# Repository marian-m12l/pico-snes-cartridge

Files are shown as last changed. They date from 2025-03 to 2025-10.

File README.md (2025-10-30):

# RP2350-based SNES cartridge

launcher

https://github.com/user-attachments/assets/8309a93a-a673-430d-9ed4-e411bfe92a66

snes_cart_1
snes_cart_2

## Pins

On rp2350 board (e.g. PGA2350):

- Address bus `A0`-`A23`: GPIO 0 (`A0`) to 23 (`A23`)
- Data bus `D0`-`D7`: GPIO 24 (`D0`) to 31 (`D7`)
- Cart pin `/CART`: GPIO 32
- Read pin `/RD`: GPIO 33
- Reset pin `/RESET`: GPIO 35
- CIC pin 24 `D1`: GPIO 37
- CIC pin 55 `D2`: GPIO 38
- CIC pin 56 `CLK`: GPIO 39
- CIC pin 25 `RST`: GPIO 40

- UART pins `TX` and `RX`: GPIO 44 and 45

## Build instructions

```
mkdir build
cd build
cmake -DPICO_SDK_PATH=/path/to/pico-sdk-2.1.0 -DPICO_BOARD=pimoroni_pga2350 ..
make
```

# Adding ROMs

Add `rom.sfc` in slot `1`:
```
./tools/loadrom.sh rom.sfc 1"
```

Each slot (from 1 to 15) occupies 1MiB in flash memory.

# Running

```
$ openocd-rpi/installed/bin/openocd -f interface/jlink.cfg -c "transport select swd" -c "adapter speed 6000" -f target/rp2350.cfg
$ arm-none-eabi-gdb -ex 'target remote localhost:3333' -ex 'load' -ex 'monitor reset init' -ex 'continue' pico-snes-cartridge.elf
$ picocom -b 115200 /dev/ttyACM0 -g picocom.log
```

# Reset behaviour

Once you've selected a game, pressing the reset button on the SNES will restart this game.

A long-press (~1 second) will go back to the launcher.

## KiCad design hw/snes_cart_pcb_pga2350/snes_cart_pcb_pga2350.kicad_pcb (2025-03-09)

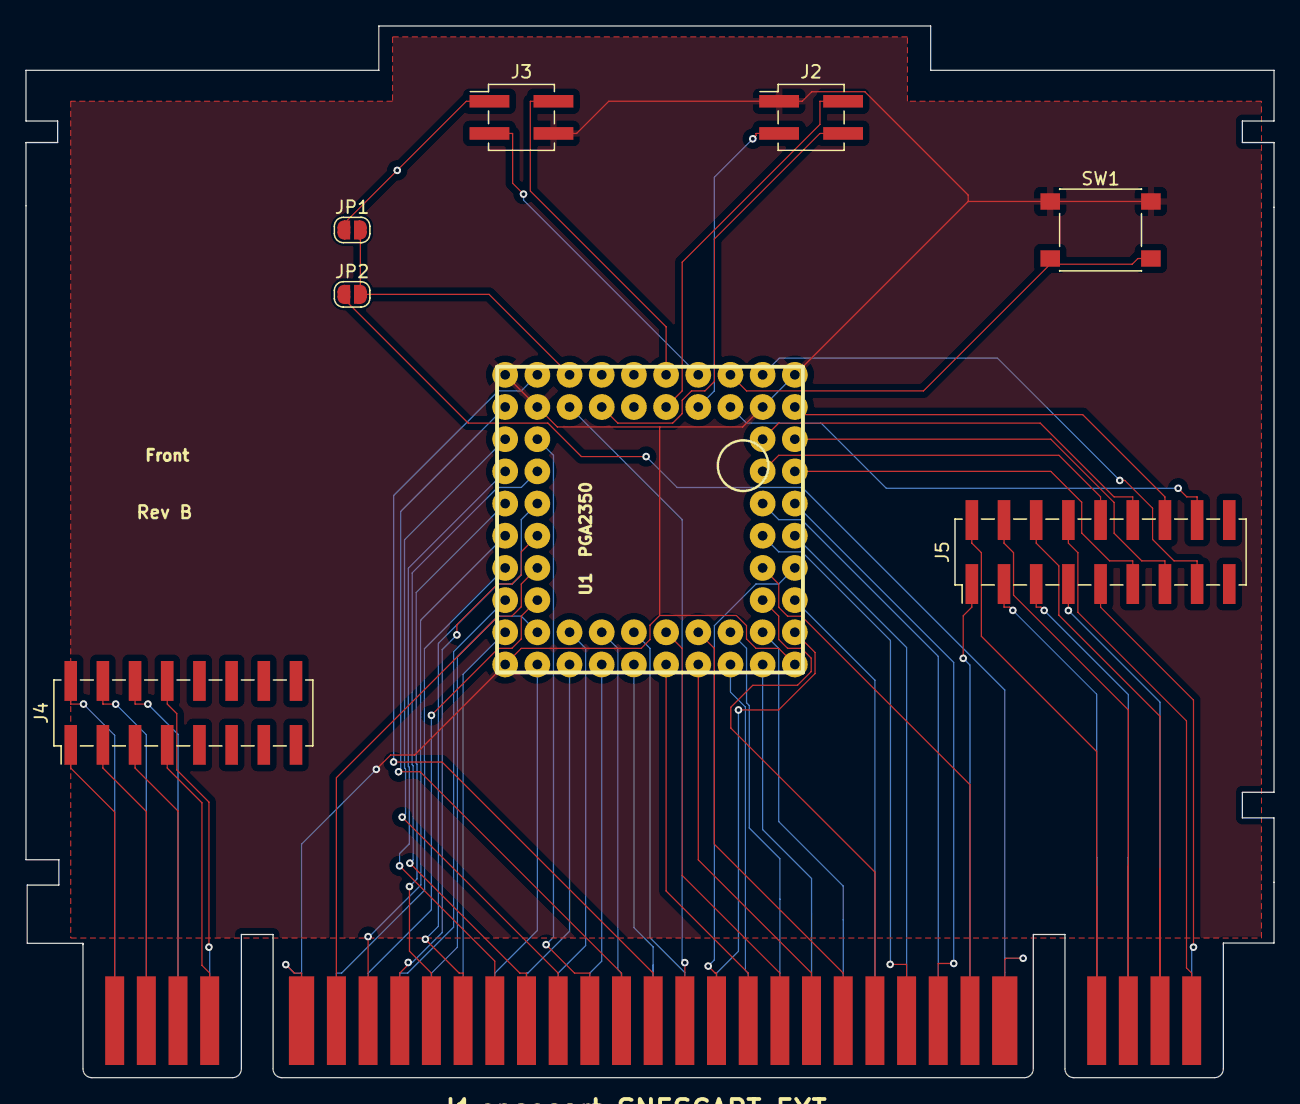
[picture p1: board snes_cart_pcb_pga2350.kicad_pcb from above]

Board: 2 copper layers, 98.5 x 83.0 mm, 9 parts (0 on the bottom side), 75 nets.

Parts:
J1: snescart_SNESCART_EXT; SNESCART_EXT_100mm
J2, J3: Conn_02x02_Counter_Clockwise; PinHeader_2x02_P2.54mm_Vertical_SMD
J4: Conn_02x08_Counter_Clockwise; PinHeader_2x08_P2.54mm_Vertical_SMD
J5: Conn_02x09_Counter_Clockwise; PinHeader_2x09_P2.54mm_Vertical_SMD
JP1, JP2: SolderJumper_2_Open; SolderJumper-2_P1.3mm_Open_RoundedPad1.0x1.5mm
SW1: SW_Push; SW_Push_1P1T_NO_6x6mm_H9.5mm
U1: PGA2350

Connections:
/3V3: J2.4, U1.B4 (PIN)
/A0: J1.17 (A0), U1.B3 (PIN)
/A1: J1.16 (A1), U1.A2 (PIN)
/A2: J1.15 (A2), U1.B1 (PIN)
/A3: J1.14 (A3), U1.C2 (PIN)
/A4: J1.13 (A4), U1.C1 (PIN)
/A5: J1.12 (A5), U1.D2 (PIN)
/A6: J1.11 (A6), U1.D1 (PIN)
/A7: J1.10 (A7), U1.E2 (PIN)
/A8: J1.9 (A8), U1.E1 (PIN)
/A9: J1.8 (A9), U1.F2 (PIN)
/A10: J1.7 (A10), U1.F1 (PIN)
/A11: J1.6 (A11), U1.G2 (PIN)
/A12: J1.37 (A12), U1.G1 (PIN)
/A13: J1.38 (A13), U1.H2 (PIN)
/A14: J1.39 (A14), U1.H1 (PIN)
/A15: J1.40 (A15), U1.J2 (PIN)
/A16: J1.41 (A16), U1.J1 (PIN)
/A17: J1.42 (A17), U1.K2 (PIN)
/A18: J1.43 (A18), U1.K3 (PIN)
/A19: J1.44 (A19), U1.J3 (PIN)
/A20: J1.45 (A20), U1.K4 (PIN)
/A21: J1.46 (A21), U1.J4 (PIN)
/A22: J1.47 (A22), U1.K5 (PIN)
/A23: J1.48 (A23), U1.J5 (PIN)
/BOOTSEL: SW1.2, U1.A8 (PIN)
/CIC_P1_DOUT: J1.24 (CIC_P1_DOUT), U1.F9 (PIN)
/CIC_P2_DIN: J1.55 (CIC_P2_DIN), U1.F10 (PIN)
/CIC_P6_CLK: J1.56 (CIC_P6_CLK), U1.E9 (PIN)
/CIC_P7_RESET: J1.25 (CIC_P7_RESET), U1.E10 (PIN)
/CPU_CLK: J1.57 (CPU_CLK), J5.1
/D0: J1.19 (D0), U1.K6 (PIN)
/D1: J1.20 (D1), U1.J6 (PIN)
/D2: J1.21 (D2), U1.K7 (PIN)
/D3: J1.22 (D3), U1.J7 (PIN)
/D4: J1.50 (D4), U1.K8 (PIN)
/D5: J1.51 (D5), U1.J8 (PIN)
/D6: J1.52 (D6), U1.K9 (PIN)
/D7: J1.53 (D7), U1.J9 (PIN)
/EXPAND: J1.2 (EXPAND), J4.3
/GND: J1.5 (GND), J1.36 (GND), J2.1, J3.4, SW1.1, U1.A1 (PIN), U1.A10 (PIN), U1.B2 (PIN), U1.B9 (PIN), U1.K1 (PIN), U1.K10 (PIN)
/GP41: J5.10, U1.D9 (PIN)
/GP42: J5.11, U1.D10 (PIN)
/GP43: J5.12, U1.C9 (PIN)
/GP44: J5.13, U1.C10 (PIN)
/GP45: J5.14, U1.B10 (PIN)
/GP46: J5.15, U1.A9 (PIN)
/GP47: J5.16, U1.B8 (PIN)
/LINE_L: J1.31 (LINE_L), J5.8
/LINE_R: J1.62 (LINE_R), J5.9
/PA0: J1.28 (PA0), J5.2
/PA1: J1.59 (PA1), J5.3
/PA2: J1.29 (PA2), J5.4
/PA3: J1.60 (PA3), J5.5
/PA4: J1.30 (PA4), J5.6
/PA5: J1.61 (PA5), J5.7
/PA6: J1.3 (PA6), J4.5
/PA7: J1.34 (PA7), J4.6
/REFRESH: J1.33 (REFRESH), J4.4
/SWCLK: J2.2, U1.B6 (PIN)
/SWDIO: J2.3, U1.B7 (PIN)
/SYS_CLK: J1.1 (SYS_CLK), J4.1
/USB_DM: J3.3, U1.A7 (PIN)
/USB_DP: J3.2, U1.A6 (PIN)
/USB_VBUS: J3.1, JP1.1 (A)
/VBUS: JP1.2 (B), JP2.2 (B), U1.A3 (PIN)
/VCC: J1.27 (VCC), J1.58 (VCC), JP2.1 (A)
//IRQ: J1.18 (/IRQ), U1.G10 (PIN)
//PARD: J1.4 (/PARD), J4.7
//PAWR: J1.35 (/PAWR), J4.8
//RD: J1.23 (/RD), U1.H9 (PIN)
//RESET: J1.26 (/RESET), U1.G9 (PIN)
//ROMSEL: J1.49 (/ROMSEL), U1.J10 (PIN)
//WR: J1.54 (/WR), U1.H10 (PIN)
//WRAM: J1.32 (/WRAM), J4.2

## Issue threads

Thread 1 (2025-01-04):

Did you try it with an actual console?

regevt, 2025-01-04:
I am very intrigued by the project. Have you tested it on a console already?

marian-m12l, 2025-01-04:
Thanks for your interest :)

Did I test on hardware? yes
Does it work yet? no

This is still very early work in progress that I started when rp2350 was released, but I couldn't get back to it lately.

From my understanding (which would be wrong of course) it seems to be reading and writing to the cartridge bus correctly, but is probably experiencing timing issues. Whenever I dump the memory addresses requested by the console, it seems to match what I'd expect (i.e. the console seems to be executing the rom code, following the expected jumps, starting the expected dma reads, reaching the main loop) but I've only rarely seen a proper screen from the test roms, which are really minimal in that they initialize the hardware and set a background color.
I'm also experiencing bad reads on pin 12 which may be related to rp2350 erratum E9. Applying the workaround on pin 12 seems to fix this issue, but I'm unsure if other pins are experiencing the same issue, and applying the workaround to all pins between every read would ruin the timing. I had planned to make a custom pcb with footprint for the PGA2350 to avoid the flywires, but haven't gotten to it yet...

If you're inclined to try it yourself, I can push anything I have locally on a branch and try to assist. Getting another pair of eyes on this could be helpful :)

regevt, 2025-01-04:
How do you connect it to the console? With jumper wires?

I would appreciate the most up-to-date code.
When I return from Japan, I probably start working on it (I bought a SFC-JR here, hence the interest).

It should work just the same using RP2040, right? If not, do you see a problem using Pico 2w? I don't have Pico 2 none W

marian-m12l, 2025-01-04:
Yes, jumper wires for now, but it's no good for signal integrity, which is why I want to design a proper PCB before investigating further.

I pushed what I have in branches `main` and `wip`. Don't expect anything stable though. I updated the readme with the actual pins used on the RP2350. RP2040 won't work as it does not have enough GPIOs: SNES has a 24-bit address bus + 8-bit data bus + a couple of control pins.

marian-m12l, 2025-01-10:
You're right. Some clarifications :

- Pico 2 won't make it either, for lack of GPIOs. You'll need a board that uses RP2350**B** and exposes all GPIOs (or at least >= 38-ish GPIOs). For instance I'm using Pimoroni PGA2350.
- I've pushed the current PCB prototype (I just ordered some) with the updated wiring, it's certainly clearer than me taking a photo of a mess of wires packed in a square inch :D
- The PCB is very rough, and I'm certain it will need several iterations before being useful. Disclaimer: I am **not** an electrical engineer (as you'll see if you open the kicad project :D)
- About logic levels: I'm not using level shifters (yet) for simplicity's sake. The RP2350 is 5V-tolerant **under some conditions** (it **has** to be powered), but there's definitely a risk here. I've operated even RP2040 with 5v logic without any issue, but I guess it's mostly luck and I wouldn't recommend this for a final product. TLDR: level shifters will be needed.
- The CIC chip, I just lifted pin 4 on the console and made sure it accepted a commercial cartridge with CIC chip removed. It will need to be emulated on the RP2350 later on.

marian-m12l, 2025-01-10:
From the RP2350 datasheet:

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

regevt, 2025-01-10:
I have a redundant Street fighter 2 cartridge that I'm going to desolder the roms (2 of them) and solder female headers instead, this way I have a solid connection and a CIC chip.
I am not willing to modify anything with the console (for now at least).
I bought this https://www.amazon.nl/dp/B0DNT15R7N?ref=ppx_yo2ov_dt_b_fed_asin_title, hopefully it will be enough.

I wander if it will be possible to use multiplexer/demultiplexer or a shift register in order to solve the pin issue.

regevt, 2025-01-16:
I am having problems programming the Pimoroni.
What do you use in order to program it?

Do you maybe want to move to a discord or any other service so we can talk more easily?

BTW, did the cartridge worked?

marian-m12l, 2025-01-17:
The PGA2350 isn't the easiest when it comes to programming.

Either solder a usb cable to VBus, GND, D+, D- and pull BOOTSEL low when connecting to your PC.

Or use a discrete programmer (STLink, JLink) wired to SWDIO/SWCLK/GND and provide 5V through VBus.

As I mentioned earlier, the cartridge is not working (yet?) and there remains _a lot_ of work, but I've seen encouraging signs looking at the addresses requested by the console. I've got PCBs on the way to hopefully improve signal integrity.

Please be aware that this is an early prototype, it may never work, and it may cause damage to the rp2350 board, SNES, or both...

I've discussed this project a bit on [this discord's #snes channel](https://discord.gg/8RQcVkY7), if you want to join.

regevt, 2025-01-17:
When I asked about the cartridge I ment the PCB, sorry.

I joined the discord and will post updates there, I plan to work on it in the weekend.

marian-m12l, 2025-03-09:
To clarify the current situation: the pcb and firmware have been confirmed to work on real hardware. ROM has to fit in RP2350 RAM, therefore it's limited to 512KiB. LoROM and HiROM are supported, as well as SlowROM and FastROM. No support for enhancement chips yet.

regevt, 2025-03-09:
I could not get any communication between the SNES and the Pico, I don't know if it's because my SNES is from Japan or my wiring is wrong.

After spending a lot of hours trying to make the basics work I decided to take a break from the project.
I am still in the discord server for when I decide to return to this.

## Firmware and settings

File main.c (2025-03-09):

#include <stdio.h>
#include <string.h>
#include "pico/stdlib.h"
#include "pico/multicore.h"
#include "hardware/clocks.h"
#include "hardware/vreg.h"
#include "hardware/dma.h"
#include "hardware/pio.h"
#include "hardware/xip_cache.h"
#include "rom.h"
#include "counter.pio.h"

//#define DEBUG 1
//#define CIC_DEBUG 1
//#define ENABLE_UART 1
#define ENABLE_CIC 1
#define ENABLE_BUS 1
//#define CHECK_ADDR_VALIDITY 1
#define FORCE_LOROM 1   // Required for FastROM
//#define FORCE_HIROM 1   // Required for FastROM

#define CIC_EXTRA_CYCLES_LEFT_RIGHT 8  //8

#ifdef DEBUG
//#define DEBUG_KEEPALIVE 1
#define COUNTER_THRESHOLD 40000
#define BUFFER_SIZE 40000
uint32_t counter = 0;
uint32_t addresses[BUFFER_SIZE];
uint8_t datas[BUFFER_SIZE];
uint32_t datas_out[BUFFER_SIZE];
uint16_t repetition[BUFFER_SIZE];
#endif

#define SNES_ADDR_PINS_MASK  0x0000000000ffffff
#define SNES_DATA_PINS_MASK  0x00000000ff000000
#define SNES_DATA_PINS_SHIFT 24

#define SNES_CART_PIN        32
#define SNES_RD_PIN          33
#define SNES_CART_PIN_MASK   0x0000000100000000
#define SNES_RD_PIN_MASK     0x0000000200000000
#define SNES_CTRL_PINS_MASK  (SNES_CART_PIN_MASK | SNES_RD_PIN_MASK)

#define SNES_CIC_P1_PIN      37
#define SNES_CIC_P2_PIN      38
#define SNES_CIC_CLK_PIN     39
#define SNES_CIC_P1_PIN_MASK 0x0000002000000000
#define SNES_CIC_P2_PIN_MASK 0x0000004000000000
#define SNES_CIC_CLK_PIN_MASK 0x0000008000000000
#define SNES_CIC_RST_PIN_MASK 0x0000010000000000
#define SNES_CIC_IO_PINS_MASK  (SNES_CIC_P1_PIN_MASK | SNES_CIC_P2_PIN_MASK)
#define SNES_CIC_PINS_MASK  (SNES_CIC_IO_PINS_MASK | SNES_CIC_CLK_PIN_MASK | SNES_CIC_RST_PIN_MASK)

// TODO Output to unused pins (41 and 42?) for debug ??
#define DEBUG_PIN            41
#define DEBUG_PINS_MASK      0x0000020000000000

#define SNES_ALL_PINS_MASK (SNES_ADDR_PINS_MASK | SNES_DATA_PINS_MASK | SNES_CTRL_PINS_MASK | SNES_CIC_PINS_MASK | DEBUG_PINS_MASK)


#define CACHE_AS_SRAM_OFFSET 0x02000000


//#define NO_LOAD 1
//#define LOAD_NO_BANKS 1
//#define LOAD_BANKS_16K 1
#define LOAD_BANKS_4K 1

#ifdef LOAD_NO_BANKS
#define ROM_MAX_LENGTH (256*1024)
uint8_t sram_rom[ROM_MAX_LENGTH];
#endif

#ifdef LOAD_BANKS_16K
#define BANK_LENGTH (16*1024)
uint8_t* xip_bank31 = (uint8_t*) (XIP_BASE+CACHE_AS_SRAM_OFFSET);
uint8_t sram_banks[31][BANK_LENGTH];
uint8_t* banks[32]; // 524288 bytes of rom data across 32 banks
#endif

#ifdef LOAD_BANKS_4K
// TODO 128 banks of 4 KiB to add USB RAM ??? 1 bank (4KiB) in USB RAM + 4 banks (16KiB) in pinned cache + 123 banks (492KiB) in main RAM
#define BANK_LENGTH (4*1024)
uint8_t* xip_banks = (uint8_t*) (XIP_BASE+CACHE_AS_SRAM_OFFSET);
uint8_t* usb_bank = (uint8_t*) (USBCTRL_DPRAM_BASE);
uint8_t sram_banks[123][BANK_LENGTH];
uint8_t* banks[128]; // 524288 bytes of rom data across 128 banks
#endif


uint8_t romtype;

#ifdef ENABLE_CIC
volatile uint32_t cic_clock_count = 0xffffffff;
#endif

#ifdef ENABLE_BUS
uint32_t map_address_to_rom(uint32_t address) {
    uint32_t bank = address >> 16;
    // FIXME address & 0x7fff or address & 0x6fff depending on (address & 0xf000) == 0xf000 ???
    if (romtype == 0) { // LoROM
        // LoROM: Up to 128 32KB-banks. Bank indexing starting from 0x80. Each bank starts at 0x8000
        // TODO Banks 70-7d --> SRAM
        if (bank >= 0x70 && bank < 0x7e) {
            return 0;
        }
        return (bank & 0x7f) * 32768 + (address & 0x7fff);
        /*if ((address & 0xf000) == 0x8000 || (address & 0xf000) == 0x9000) {
            return (bank & 0x7f) * 32768 + (address & 0x6fff);
        } else {
            return (bank & 0x7f) * 32768 + (address & 0x7fff);
        }*/
    } else if (romtype == 1) {  // HiROM
        // HiROM: Up to 64 64KB-banks. Bank indexing starting from 0xc0. Each bank starts at 0x0000
        // TODO Handle ROM mirror ?
        return (bank & 0x3f) * 65536 + (address & 0xffff);
    } else {
        // TODO Add support for ExHiROM
        return (bank & 0x3f) * 65536 + (address & 0xffff);
    }
}
#endif

/*
inline void gpio_set_ie(bool enabled) {
    // FIXME which pins need IE disabled ??
    gpio_set_input_enabled(12, enabled);
    //gpio_set_input_enabled(16, enabled);
    //gpio_set_input_enabled(18, enabled);
    //gpio_set_input_enabled(20, enabled);
    //gpio_set_input_enabled(22, enabled);
}

inline void gpio_disable_ie() {
    gpio_set_ie(false);
}

inline void gpio_enable_ie() {
    gpio_set_ie(true);
}
*/



#ifdef ENABLE_CIC

// TODO From https://github.com/mrehkopf/sd2snes/blob/develop/cic/mangle.c

#define CARRY	if(a>0x0f) {\
			a &= 0xf;\
			carry=1;\
		} else carry=0;

#define CYCLES_COUNT_SKIP (84)
#define CYCLES_COUNT_NOSKIP (78)

uint mangle(unsigned char* data) {
	unsigned char a,x,temp,i,offset,carry=0;
	a=data[0xf];
    // TODO Count cycles / iterations ?
    uint cycles = 0;
	do {
		x=a;
		offset=1;
		carry=1;
		a+=data[offset]+carry;
		data[offset]=a&0xf;
		a=data[offset++];
		a+=data[offset]+carry;
		a=(~a)&0xf;
		temp=a; a=data[offset]; data[offset++]=temp&0xf;
		a+=data[offset]+carry;
		if(a<0x10) {
            // TODO "no-skip" cycles count (78)
            cycles += CYCLES_COUNT_NOSKIP;
			temp=a; a=data[offset]; data[offset++]=temp&0xf;
		} else {
            // TODO Else "skip" cycles count (84)
            cycles += CYCLES_COUNT_SKIP;
        }
		a+=data[offset];
		data[offset]=a&0xf;
		a=data[offset++];
		carry=0;
		a+=data[offset]+carry;
		temp=a; a=data[offset]; data[offset++]=temp&0xf;
		a+=8;
		if(a<0x10) {
			a+=data[offset]+carry;
		}
		temp=a; a=data[offset]; data[offset++]=temp&0xf;

		while(offset<0x10) {
			a++;
			a+=data[offset]+carry;
			data[offset]=a&0xf;
			a=data[offset++];
		}
		offset &= 0xf;
		a=x;
		a+=0xf;
		CARRY;
	} while(carry);

    return cycles;
}


#ifdef CIC_DEBUG
#define BUFSIZE 1024

uint32_t mangles[BUFSIZE];
uint32_t delays[BUFSIZE];
uint32_t timings[BUFSIZE];
uint32_t timings_end[BUFSIZE];
#endif


static inline void wait_until_clock_pulses(uint32_t until) {
    // TODO Handle counter overflow/underflow?
    while(~cic_clock_count < until) {
        tight_loop_contents();
    }
}

static inline void wait_clock_pulses(uint32_t count) {
    wait_until_clock_pulses(~cic_clock_count + count);
}

// code for core1
void core1_entry() {

    // TODO One-time initialization ??

    gpio_set_dir_masked64(DEBUG_PINS_MASK, DEBUG_PINS_MASK);
    gpio_put_masked64(DEBUG_PINS_MASK, 0x0000000000000000);
    
    while (true) {
        // CIC Emulation
#ifdef ENABLE_UART
        printf("Starting CIC emulation...\n");
#endif

#ifdef CIC_DEBUG
        gpio_put(DEBUG_PIN, 1);
#endif

        // TODO Use IRQ to reset CIC when RST goes up? (e.g. when resetting the console manually?)

        // Setup clock pulses counter (CIC clock may be 4MHz, 3.58MHz, 3.54MHz, or 3.072MHz)
        cic_clock_count = 0xffffffff;
        uint32_t wait_next;
        uint8_t seed = 0;

        // Setup PIO counter
        PIO pio;
        uint offset;
        uint sm;
        bool success = pio_claim_free_sm_and_add_program_for_gpio_range(&counter_program, &pio, &sm, &offset, SNES_CIC_CLK_PIN, 1, true);
        if (!success) {
#ifdef ENABLE_UART
            printf("Failed to initialize PIO\n");
#endif
            goto cic_die;
        }
        counter_program_init(pio, sm, offset, SNES_CIC_CLK_PIN);

        // Setup counter DMA
        int dma_chan = dma_claim_unused_channel(true);
        int dma_chan2 = dma_claim_unused_channel(true);

        // Channel 1, this starts and than hands over to the second channel when it is done
        // Channel 2 then hands back to channel 1, so we get a continous DMA stream to a single target variable
        dma_channel_config dc = dma_channel_get_default_config(dma_chan);
        channel_config_set_transfer_data_size(&dc, DMA_SIZE_32);
        channel_config_set_read_increment(&dc, false);
        channel_config_set_write_increment(&dc, false);
        channel_config_set_chain_to(&dc, dma_chan2);
        channel_config_set_dreq(&dc, pio_get_dreq(pio, sm, false));
        dma_channel_configure(dma_chan, &dc,
            &cic_clock_count,
            &pio->rxf[sm],
            0xffffffff,
            true
        );

        // Channel 2 as above
        dma_channel_config dc2 = dma_channel_get_default_config(dma_chan2);
        channel_config_set_transfer_data_size(&dc2, DMA_SIZE_32);
        channel_config_set_read_increment(&dc2, false);
        channel_config_set_write_increment(&dc2, false);
        channel_config_set_dreq(&dc2, pio_get_dreq(pio, sm, false));
        channel_config_set_chain_to(&dc2, dma_chan);
        dma_channel_configure(dma_chan2, &dc2,
            &cic_clock_count,
            &pio->rxf[sm],
            0xffffffff,
            false
        );

        unsigned char lockseed[16]={0x0, // dummy
                    0xb,0x1,0x4,0xf,
                    0x4,0xb,0x5,0x7,
                    0xf,0xd,0x6,0x1,
                    0xe,0x9,0x8};
        unsigned char keyseed[16]={0x0, // dummy
                    0x0, // fill-in value sent by lock on reset in bit order 3-0-1-2
                    0x6,0xa,0x1,   // PAL
                    //0x9,0xa,0x1,  // TODO Add support for NTSC
                    0x8,0x5,0xf,0x1,
                    0x1,0xe,0x1,0x0,
                    0xd,0xe,0xc};
        unsigned char restart = 1, swap = 0;

        // GPIO setup: initial configuration: P1 is key output, P2 is key input (Pin 55 (P2) is **GPIO 0** in PIC CIC clone code)
        // Lock sends seed over P2 / D2 / Pin55
        gpio_set_dir_masked64(SNES_CIC_IO_PINS_MASK, SNES_CIC_P1_PIN_MASK);
        gpio_put_masked64(SNES_CIC_IO_PINS_MASK, 0x0000000000000000);
        
        // Wait for CIC RST to raise
#ifdef ENABLE_UART
        printf("Waiting for CIC reset...\n");
#endif
        while((gpio_get_all64() & SNES_CIC_RST_PIN_MASK) == 0) {
            tight_loop_contents();
        }
        // Start counting clock pulses on RST falling edge
        while((gpio_get_all64() & SNES_CIC_RST_PIN_MASK) != 0) {
            tight_loop_contents();
        }
        pio_sm_set_enabled(pio, sm, true);

#ifdef CIC_DEBUG
        //printf("CIC start\n");
        gpio_put(DEBUG_PIN, 0);
#endif

        /*uint32_t wait = 1000;
        int dbg = 1;
        while (true) {
            // TODO switch debug pin every 1000 cic pulses
            wait_until_clock_pulses(wait);
            gpio_put(DEBUG_PIN, dbg);
            dbg = !dbg;
            wait += 1000;
        }*/

        // Read seed nibble a.k.a. stream id (transmission bit order is 3-0-1-2. e.g. '1-0-1-1' => 0xe)
        wait_next = 632 * 4;    // FIXME 635 * 4;
        wait_until_clock_pulses(wait_next);
#ifdef CIC_DEBUG
        gpio_put(DEBUG_PIN, 1);
#endif
        keyseed[1] |= gpio_get(SNES_CIC_P2_PIN) << 3;
        wait_next += 15 * 4;
        wait_until_clock_pulses(wait_next);
        keyseed[1] |= gpio_get(SNES_CIC_P2_PIN);
        wait_next += 15 * 4;
        wait_until_clock_pulses(wait_next);
        keyseed[1] |= gpio_get(SNES_CIC_P2_PIN) << 1;
        wait_next += 15 * 4;
        wait_until_clock_pulses(wait_next);
        keyseed[1] |= gpio_get(SNES_CIC_P2_PIN) << 2;
#ifdef CIC_DEBUG
        gpio_put(DEBUG_PIN, 0);
#endif

        //printf("CIC seed=0x%01x\n", keyseed[1]);

        seed = keyseed[1];

        // wait (instruction) cycles until main loop: 133

        // wait (instruction) cycles in main loop:
        //  - (a) 1 cycle (loop overhead)
        //  - (b) 2 cycles (loop0 overhead)
        //  - (c) 8 cycles until GPIO out within loop1
        //  - 3 cycles output
        //  - 82 cycles until loop1 loopback to (c)
        //  - OR 94 cycles until calls to mangle (if looping in loop1)
        //      - mangle cycles vary (use return value)
        //      - 15 cycles until loop0 loopback to (b)
        //      - OR 16 cycles until loop0 loopback to (a)

        // wait (instruction) cycles before first loop1 output: 11 cycles (--> 44 cic cycles)
        // wait (instruction) cycles between loop1 outputs: 3 + 82 + 8 = 93 instruction cycles (--> 372 cic cycles)
        // wait (instruction) cycles between last loop1 output and next loop0 output: 3 + 94 + mangle (anywhere between 468 and 504 PER MANGLE LOOP (+ mangle call overhead ~18 ???)) + ((15 + 2) OR (16 + 3 if offset=0)) + 2
        // TODO Between ~10k and ~18k cic pulses in logic analyzer captures

        // FIXME Count again?

        // FIXME Should output the first values on D2 ???
        gpio_set_dir_masked64(SNES_CIC_IO_PINS_MASK, SNES_CIC_P2_PIN_MASK);
        gpio_put_masked64(SNES_CIC_IO_PINS_MASK, 0x0000000000000000);

        wait_next += 130 * 4;   // FIXME 134 * 4;
        
        // Output up to 15 keyseed bits in locksteps, mangling seed whenever we reach the last bit
        uint16_t idx = 0;
        while (true) {
            wait_next += 2 * 4;
            // Output keyseed (starting at index 'restart') until last bit is reached
            bool first = true;
            bool adjusted = false;
            bool die = false;
            while (restart < 16) {
                // FIXME DEBUG
                unsigned char output = keyseed[restart] & 1;
                unsigned char input = lockseed[restart] & 1;
                // FIXME wait_next += 8 * 4;
                wait_until_clock_pulses(wait_next);
                wait_next += CIC_EXTRA_CYCLES_LEFT_RIGHT * 4; // FIXME
                // Output keyseed bit to P2 or P1
#ifdef CIC_DEBUG
                if (first) {
                    delays[idx%BUFSIZE] = wait_next;
                    timings[idx%BUFSIZE] = ~cic_clock_count + 8*4;
                    first = false;
                }
                gpio_put(DEBUG_PIN, 1);
#endif
                gpio_put(swap ? SNES_CIC_P1_PIN : SNES_CIC_P2_PIN, output);
                restart++;
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
int main() {

#ifdef ENABLE_BUS
    // Overclock
    vreg_set_voltage(VREG_VOLTAGE_1_20);
    set_sys_clock_khz(330000, true);
#endif

#ifdef ENABLE_UART
    stdio_init_all();
#endif

    //sleep_ms(5000);

#ifdef ENABLE_UART
    printf("TEST TEST TEST\n");
#endif

    //sleep_ms(1000);


// No pinning if reading ROM from flash
#if defined(LOAD_BANKS_16K) || defined(LOAD_BANKS_4K)
#ifdef ENABLE_UART
    printf("Pinning 16K of cache lines\n");
    //sleep_ms(1000);
#endif
    // TODO Pin XIP cache lines to use another 16KB of SRAM
    // TODO Use USB SRAM (4KB) since we're not using USB anyway
    // TODO Total amount of usable RAM: 520 + 16 + 4 = 540 KB (+1 KB of Boot RAM if we _really_ need it...
    // TODO Make the code fit in 28 KB ?? --> remove debug buffers ? 16 KB)
    // TODO Need to load ROM data from flash into pinned cache lines and USB RAM ?? --> mark rom data as flash only + handle the whole copying manually at boot time
    // TODO Use __in_flash() attribute
    // TODO Should be able to fit 512 KB ROMs with no additional chip and Slow ROM --> F-Zero, Final Fantasy: Mystic Quest, SMW, ...
    // TODO Leave 8 KB of RAM for SRAM saves ?? up to 32 KB ??? --> of use PSRAM maybe ?? timing constraints on SRAM reads ??? same as ROM ??
    // FIXME Need custom ld script to use the scratch sram banks (2 * 4KiB) ???

    // Pin cache lines for an additional 16 KiB of RAM
    //printf("Pinning 16KB of XIP cache at address 0x%08x\n", xip_bank31);
    //xip_cache_maintenance(CACHE_AS_SRAM_OFFSET, 16*1024, XIP_CACHE_PIN_AT_ADDRESS);
    xip_cache_pin_range(CACHE_AS_SRAM_OFFSET, 16*1024);
    /*for (int line=0; line<2048; line++) {
        char* maintenance_addr = (char*) (XIP_MAINTENANCE_BASE + CACHE_AS_SRAM_OFFSET + line*8 + 7);
        *maintenance_addr = 1;
    }*/
#ifdef ENABLE_UART
    printf("Pinned\n");
    //sleep_ms(1000);
#endif
#endif


#ifdef LOAD_NO_BANKS
    int size = rom_size;
    if (size > ROM_MAX_LENGTH) {
#ifdef ENABLE_UART
        printf("Unsupported ROM size: %d > %d\n", size, ROM_MAX_LENGTH);
    //sleep_ms(1000);
#endif
        size = ROM_MAX_LENGTH;
    }
#ifdef ENABLE_UART
    printf("Loading %d bytes ROM\n", size);
    //sleep_ms(1000);
#endif
    memcpy(sram_rom, rom, size);
#ifdef ENABLE_UART
    printf("Loaded\n");
    //sleep_ms(1000);
#endif
#endif

#ifdef LOAD_BANKS_16K
    for (int i=0; i<31; i++) {
        banks[i] = sram_banks[i];
    }
    banks[31] = xip_bank31;
    // TODO Bank 31 will NOT be zero-initialized by the BSS routine
    memset(xip_bank31, 0, BANK_LENGTH);
    // Load ROM into RAM
    int banks_count = rom_size / BANK_LENGTH;
    if (banks_count > 32) {
#ifdef ENABLE_UART
        printf("Unsupported ROM size: %d banks > %d\n", banks_count, 32);
    //sleep_ms(1000);
#endif
        banks_count = 32;
    }
#ifdef ENABLE_UART
    printf("Loading %d ROM banks\n", banks_count);
    //sleep_ms(1000);
#endif
    for (int i=0; i<banks_count; i++) {
        memcpy(banks[i], rom + i*BANK_LENGTH, BANK_LENGTH);
    }
#ifdef ENABLE_UART
    printf("Loaded\n");
    //sleep_ms(1000);
#endif
#endif

#ifdef LOAD_BANKS_4K
    // FIXME Should reset USB controller before accessing USB DPRAM @ 0x50100000 ??
    // TODO bit 28 of RESETS ??
    /*
    You can store general user data in USB DPRAM space not required for USB controller operation. When the controller is
    disabled, all 4 kB of DPRAM is available. Before accessing the DPRAM, you must take the USB controller out of reset.
    */

#ifdef ENABLE_UART
    printf("Loading ROM into 4K banks\n");
    //sleep_ms(1000);
#endif

    for (int i=0; i<123; i++) {
        banks[i] = sram_banks[i];
    }
    banks[123] = xip_banks;
    banks[124] = xip_banks + BANK_LENGTH;
    banks[125] = xip_banks + 2*BANK_LENGTH;
    banks[126] = xip_banks + 3*BANK_LENGTH;
    banks[127] = usb_bank;
#ifdef ENABLE_UART
    printf("Zeroing cache RAM\n");
    //sleep_ms(1000);
#endif
    // TODO Banks 123+ will NOT be zero-initialized by the BSS routine
    memset(xip_banks, 0, 4*BANK_LENGTH);
#ifdef ENABLE_UART
    printf("Zeroing USB RAM\n");
    //sleep_ms(1000);
#endif
    memset(usb_bank, 0, BANK_LENGTH);
#ifdef ENABLE_UART
    printf("Calculating banks count\n");
    //sleep_ms(1000);
#endif
    // Load ROM into RAM
    int banks_count = rom_size / BANK_LENGTH;
#ifdef ENABLE_UART
    printf("ROM size: %d Banks count: %d\n", rom_size, banks_count);
    //sleep_ms(1000);
#endif
    if (banks_count > 128) {
#ifdef ENABLE_UART
        printf("Unsupported ROM size: %d banks > %d\n", banks_count, 128);
#endif
        banks_count = 128;
    }
#ifdef ENABLE_UART
    printf("Loading %d ROM banks\n", banks_count);
#endif
    for (int i=0; i<banks_count; i++) {
        memcpy(banks[i], rom + i*BANK_LENGTH, BANK_LENGTH);
    }
#ifdef ENABLE_UART
    printf("Loaded\n");
#endif
#endif

#if defined(LOAD_BANKS_16K) || defined(LOAD_BANKS_4K)
    // TODO Check RAM content !!
    for (int i=0; i<banks_count; i++) {
        if (memcmp(banks[i], rom + i*BANK_LENGTH, BANK_LENGTH) != 0) {
#ifdef ENABLE_UART
            printf("Mismatch between RAM banks and ROM in flash\n");
#endif
        }
    }

    // TODO Output some data from ram banks ??
#ifdef ENABLE_UART
    for (int i=0; i<banks_count; i++) {
        printf("Bank 0x%02x @ 0x%08x: %02x %02x %02x %02x %02x %02x %02x %02x %02x %02x %02x %02x %02x %02x %02x %02x\n",
                    i, banks[i],
                    banks[i][0], banks[i][1], banks[i][2], banks[i][3], banks[i][4], banks[i][5], banks[i][6], banks[i][7],
                    banks[i][8], banks[i][9], banks[i][10], banks[i][11], banks[i][12], banks[i][13], banks[i][14], banks[i][15]
        );
    }
#endif
#endif


#ifdef ENABLE_CIC
    // Start core1 with CIC emulator
    multicore_launch_core1(core1_entry);
#endif


#ifdef ENABLE_BUS
    // Configure GPIOs
    gpio_set_dir_masked64(SNES_ALL_PINS_MASK, 0x0000000000000000);
    gpio_put_masked64(SNES_ALL_PINS_MASK, 0x0000000000000000);
    gpio_set_function_masked64(SNES_ALL_PINS_MASK, GPIO_FUNC_SIO);

    // TODO disable hysteresis on /CART and /CART to shave off 2 cycles of latency??
    gpio_set_input_hysteresis_enabled(SNES_CART_PIN, false);
    gpio_set_input_hysteresis_enabled(SNES_RD_PIN, false);


    // FIXME Required ??
    gpio_set_slew_rate(SNES_DATA_PINS_SHIFT, GPIO_SLEW_RATE_FAST);
    gpio_set_slew_rate(SNES_DATA_PINS_SHIFT+1, GPIO_SLEW_RATE_FAST);
    gpio_set_slew_rate(SNES_DATA_PINS_SHIFT+2, GPIO_SLEW_RATE_FAST);
    gpio_set_slew_rate(SNES_DATA_PINS_SHIFT+3, GPIO_SLEW_RATE_FAST);
    gpio_set_slew_rate(SNES_DATA_PINS_SHIFT+4, GPIO_SLEW_RATE_FAST);
    gpio_set_slew_rate(SNES_DATA_PINS_SHIFT+5, GPIO_SLEW_RATE_FAST);
    gpio_set_slew_rate(SNES_DATA_PINS_SHIFT+6, GPIO_SLEW_RATE_FAST);
    gpio_set_slew_rate(SNES_DATA_PINS_SHIFT+7, GPIO_SLEW_RATE_FAST);
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

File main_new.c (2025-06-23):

#include <stdio.h>
#include "pico/stdlib.h"
#include "pico/multicore.h"
#include "hardware/clocks.h"
#include "hardware/vreg.h"
#include "hardware/watchdog.h"

#include "bus.h"
#include "cic.h"
#include "pins.h"
#include "launcher.h"


#ifdef RESET_TO_LAUNCHER

void reset_gpio_callback(uint gpio, uint32_t events) {
    // Called when RESET is pressed (low)
    // Wait for RESET to be released (high) or for the long-press reset-to-launcher timeout
    uint32_t counter = 1000000;
    while (--counter && !gpio_get(SNES_RESET_PIN)) {
        tight_loop_contents();
    }
    if (counter == 0) {
        // Just reset RP2350 (into launcher)
        watchdog_reboot(0, 0, 0);
    }
}
#endif

#ifdef ENABLE_CIC
void core1_entry() {
    // Wait until core0 is done playing with cache pinning (this would make CIC crash when trying to read from flash)
    multicore_fifo_pop_blocking();

    while (true) {
        if (init_cic()) {
            loop_cic();
            deinit_cic();
        }
    }
}
#endif

int main() {
    // Overclock to 330MHz
    vreg_set_voltage(VREG_VOLTAGE_1_20);
    set_sys_clock_khz(330000, true);

#ifdef ENABLE_UART
    stdio_init_all();
#endif

#ifdef ENABLE_CIC
    // Start core1 with CIC emulator
    multicore_launch_core1(core1_entry);
#endif

#ifdef ENABLE_BUS
    // Configure GPIOs
    gpio_set_dir_masked64(SNES_ALL_PINS_MASK, 0x0000000000000000);
    gpio_put_masked64(SNES_ALL_PINS_MASK, 0x0000000000000000);
    gpio_set_function_masked64(SNES_ALL_PINS_MASK, GPIO_FUNC_SIO);

    // Disable hysteresis on /CART and /RD to shave off 2 cycles of latency
    gpio_set_input_hysteresis_enabled(SNES_CART_PIN, false);
    gpio_set_input_hysteresis_enabled(SNES_RD_PIN, false);

    gpio_set_slew_rate(SNES_DATA_PINS_SHIFT, GPIO_SLEW_RATE_FAST);
    gpio_set_slew_rate(SNES_DATA_PINS_SHIFT+1, GPIO_SLEW_RATE_FAST);
    gpio_set_slew_rate(SNES_DATA_PINS_SHIFT+2, GPIO_SLEW_RATE_FAST);
    gpio_set_slew_rate(SNES_DATA_PINS_SHIFT+3, GPIO_SLEW_RATE_FAST);
    gpio_set_slew_rate(SNES_DATA_PINS_SHIFT+4, GPIO_SLEW_RATE_FAST);
    gpio_set_slew_rate(SNES_DATA_PINS_SHIFT+5, GPIO_SLEW_RATE_FAST);
    gpio_set_slew_rate(SNES_DATA_PINS_SHIFT+6, GPIO_SLEW_RATE_FAST);
    gpio_set_slew_rate(SNES_DATA_PINS_SHIFT+7, GPIO_SLEW_RATE_FAST);

    // Hold console in reset until rom is loaded and loop is started
    gpio_put(SNES_RESET_PIN, 0);
    gpio_set_drive_strength(SNES_RESET_PIN, GPIO_DRIVE_STRENGTH_12MA);
    gpio_set_dir(SNES_RESET_PIN, true);

#ifdef RESET_TO_LAUNCHER
    // Register RESET interrupt handler
    gpio_set_irq_callback(&reset_gpio_callback);
    irq_set_enabled(IO_IRQ_BANK0, true);
#endif

    // Look for ROMs in flash memory
    find_rom_entries();

    // Load menu and loop
    uint8_t romtype = init_rom(launcher_rom, launcher_rom_size);

#ifdef ENABLE_CIC
    // Start CIC once we're done loading rom (and pinning xip cache)
    multicore_fifo_push_blocking(0xc1c0c1c0);
#endif

    // Release reset on console
    gpio_set_dir(SNES_RESET_PIN, false);

    loop_launcher();

    // Rom was selected, load and run loop
    uint8_t* selected = selected_rom();
    if (selected != 0) {
        // Hold console in reset until rom is loaded and loop is started
        gpio_set_dir(SNES_RESET_PIN, true);

        uint32_t size = *((uint32_t*) (selected + 16));
        uint8_t romtype = init_rom(selected + 32, size);

#ifdef RESET_TO_LAUNCHER
        gpio_set_irq_enabled(SNES_RESET_PIN, GPIO_IRQ_EDGE_FALL, true);
#endif
        
        // Release reset on console
        gpio_set_dir(SNES_RESET_PIN, false);

        if (romtype == 0) { // LoROM
            loop_lorom();
        } else if (romtype == 1) {  // HiROM
            loop_hirom();
        }
    }
#endif

    while(true) {
        tight_loop_contents();
    }
    return 0;
}

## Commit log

2025-01-04 (wip) erratum e9 workaround for pin 12
    [main.c]
2025-01-05 add pcb design
    [snes_cart_pcb_pga2350-B_Cu.gbr, snes_cart_pcb_pga2350-B_Mask.gbr, snes_cart_pcb_pga2350-B_Paste.gbr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]
2025-01-18 works on pcb rev1
2025-02-13 (wip) initial support for cic on core1
    [snes_cart_pcb_pga2350.kicad_pcb, snes_cart_pcb_pga2350.kicad_sch]
2025-03-07 fix header detection + fix hirom mapping + run rom with cic code enabled (wip)
    [main.c]
2025-04-17 tool lists slots
2025-06-23 fix reset-to-launcher with long-press of reset button
    [bus.c, main_new.c]
2025-10-30 Update README.md add board pictures
